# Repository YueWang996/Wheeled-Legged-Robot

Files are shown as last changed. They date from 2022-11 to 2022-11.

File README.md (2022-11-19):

# Wheeled Legged Robot
A low cost wheeled legged robot driven by BLDC motor and Feetech serial servos.
## Project Introduction
There are two branches in this project--_Main_ and _MotorDriver_

- Branch [Main](https://github.com/YueWang996/Wheeled-Legged-Robot/tree/main) contains code for the main control unit. It contains an ESP32 board and an MPU6050 6-DOF IMU. 
- Brance [MotorDriver](https://github.com/YueWang996/Wheeled-Legged-Robot/tree/MotorDriver) contains code based on SimpleFOC for the motor control board. It is a dual-channel BLDC motor controller which can control two BLDC motors at the same time. The onboard CAN transceiver receives instructions from the main control unit so that the two motors can move as desired. 

## Environment
- ESP-IDF 4.2
- CLion 2021.2.3
- Python 3.9

Maybe you can refer to [this link (Chinese version)](https://www.bilibili.com/read/cv15226500) to get more information about how to configure and use ESP-IDF toolchain in Clion. 

## Major Hardwares
- ESP32-WROOM-32D
- Feetech ST3215 serial servo * 4
- Feetech servo control board
- GY-521 (MPU6050)

## Project Structure
All source code is placed in the [src](https://github.com/YueWang996/Wheeled-Legged-Robot/tree/main/src).
 * [src](./src)
   * [CAN](./src/CAN) - CAN bus initialisation;
   * [MPU6050](./src/MPU6050) - MPU6050 drivers;
   * [ServoSDK](./src/ServoSDK) - Feetech servo driver modified for ESP32;
   * [imu.h/.cpp](./src) - IMU data acquire;
   * [Kalman.h/.cpp](./src) - A Kalman filter for data fusion of accelerometer and gyroscope readings from MPU6050, from TKJ Electronics;
   * [LowPass.h](./src) - A lowpass filter library from [here](https://github.com/curiores/ArduinoTutorials/blob/main/LowPass2.0/LowPass2.0.ino);
   * [MotorControl.h/.cpp](./src) - Controlling two BLDC motors and 4 servos to the desired position via CAN bus and serial port. Inverse kinematics is used to calculate servo positions;
   * [WebPage.h](./src) - HTML code for web interface rendering;
   * [Config.h](./src) - Some predefined static variables and data types;
   * [main.cpp](./src) - Main entrance of the program. COntaining the LQR controller.

All model files are stored in the directory [Models](https://github.com/YueWang996/Wheeled-Legged-Robot/tree/main/Models). They are already verified by 3D printing.

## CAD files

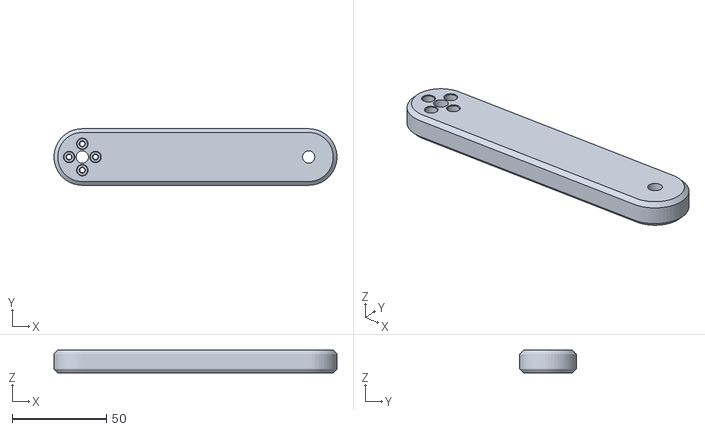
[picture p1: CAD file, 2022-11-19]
Models/leg_outside_up_servo.stl
150.0 x 30.0 x 12.0

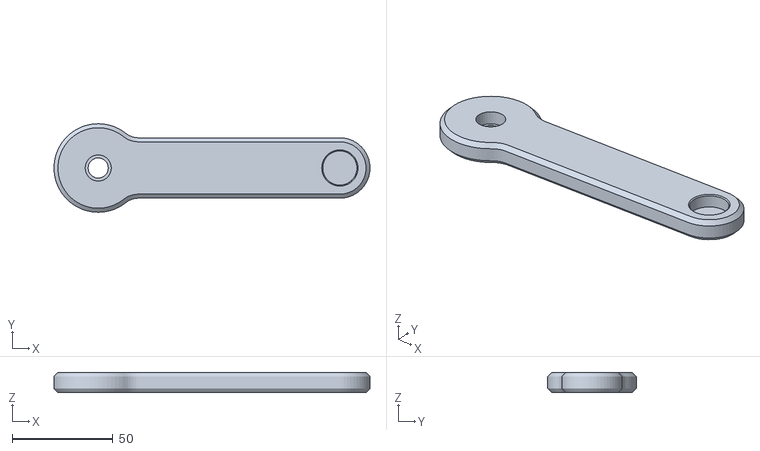
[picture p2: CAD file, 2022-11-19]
Models/leg_outside.stl
156.9 x 44.0 x 10.0

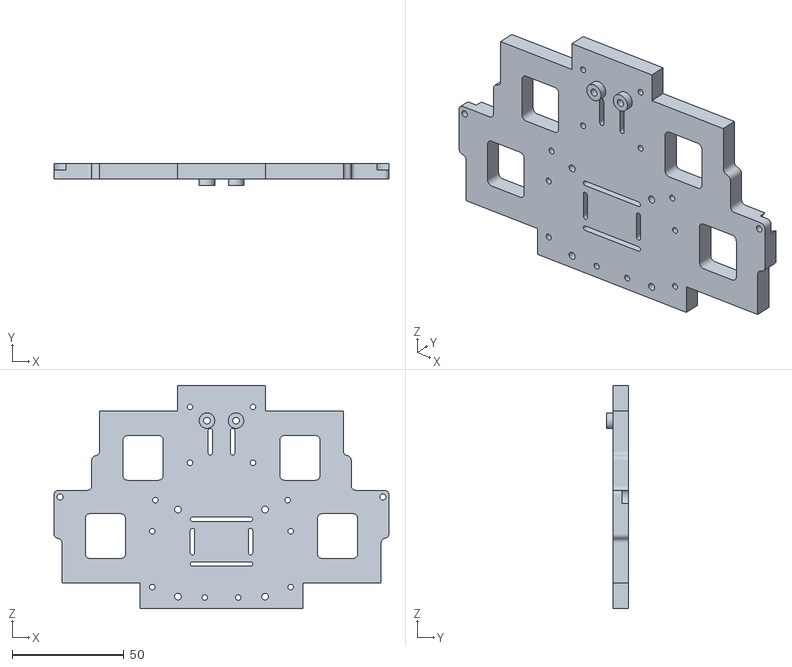
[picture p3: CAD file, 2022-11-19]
Models/body_base_servo.stl
150.0 x 10.0 x 100.0

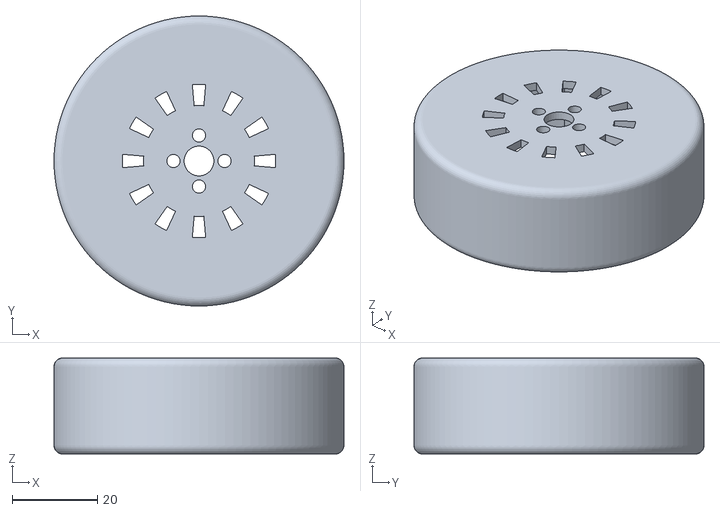
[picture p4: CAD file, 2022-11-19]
Models/wheel2.stl
68.0 x 68.0 x 22.5

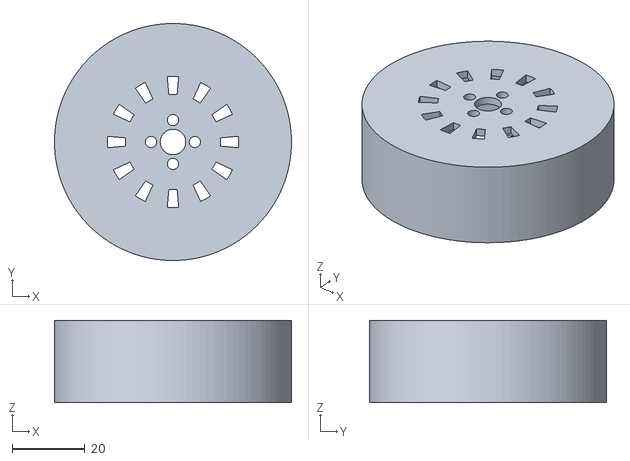
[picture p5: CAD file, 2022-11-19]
Models/wheel.stl
65.0 x 65.0 x 22.5

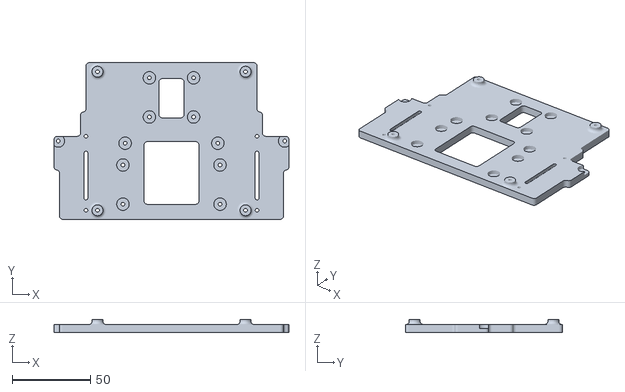
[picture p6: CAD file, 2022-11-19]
Models/body_top_servo.stl
150.0 x 100.0 x 8.00

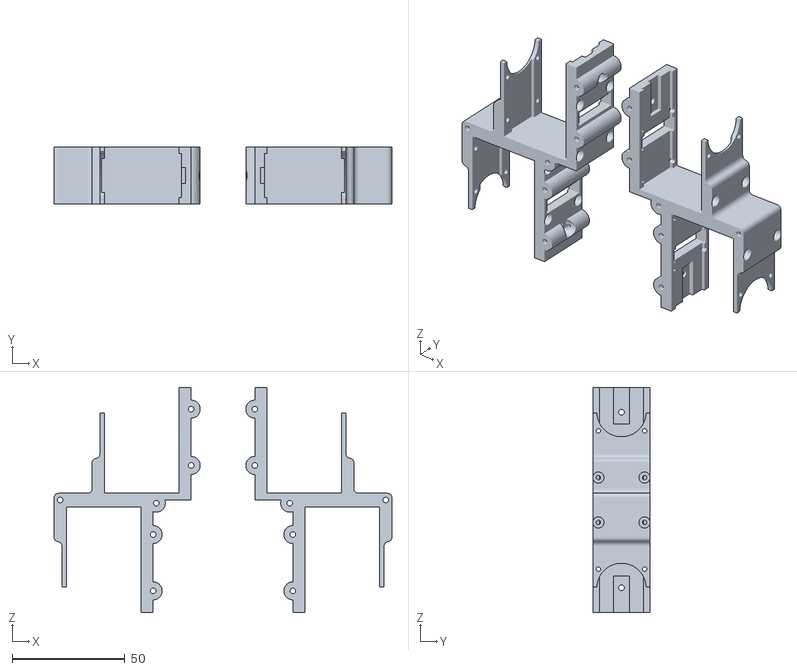
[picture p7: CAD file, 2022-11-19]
Models/body_servo.stl
150.0 x 25.5 x 100.0

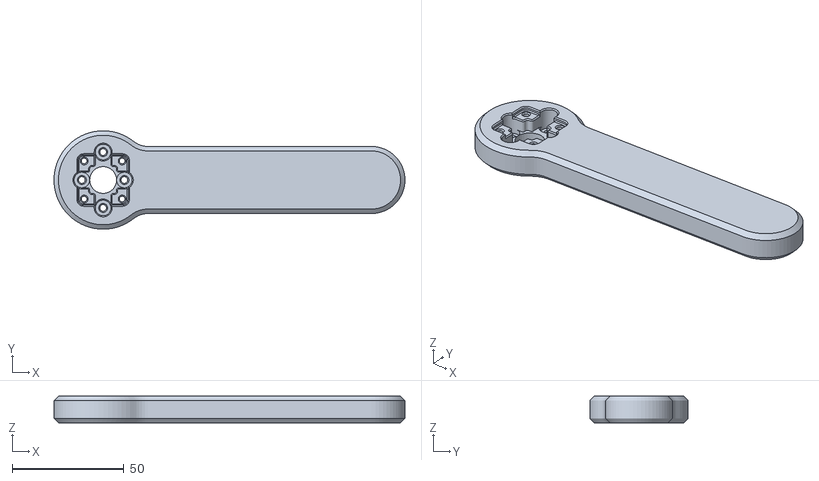
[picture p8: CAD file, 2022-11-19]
Models/leg_inside.stl
156.9 x 44.0 x 12.0

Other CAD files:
Models/leg_inside_up.stl
Models/leg_inside_up_servo.stl
Models/leg_outside_up.stl

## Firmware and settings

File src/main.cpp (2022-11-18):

#include <Arduino.h>
#include "freertos/FreeRTOS.h"
#include "freertos/task.h"
#include "freertos/timers.h"
#include "CAN/CAN_config.h"
#include "CAN/ESP32CAN.h"
#include "MotorControl.h"
#include "IMU.h"
#include "Kalman.h"
#include "soc/timer_group_struct.h"
#include "WebPage.h"

#include <WiFi.h>
#include <WebServer.h>
#include <sstream>

// #define WIFI_DEBUG

#ifdef WIFI_DEBUG
const char* ssid = "VM2866187";
const char* password = "tk8vyPczhfhr";
#else
const char* ap_ssid = "MengMengRobot";
const char* ap_password = "12345678";
#endif


WebServer server(80);

IPAddress PageIP(192, 168, 1, 1);
IPAddress gateway(192, 168, 1, 1);
IPAddress subnet(255, 255, 255, 0);
float target_position = 0;
float target_angle = 0;
float target_velocity = 0;
float height = 150.0;
bool ifJump = false;

CAN_device_t CAN_cfg;                // CAN Config
int rx_queue_size = 10;       // Receive Queue size

MotorControl motorControl;

IMU imu;
Kalman kalmanRoll;
Kalman kalmanPitch;
SCSCL sc(0);


static SIX_CHANNEL_BWLPF *bwlpf;
static float pitch, roll;
static double gyroXangle, gyroYangle; // Angle calculate using the gyro only
static double kalAngleX, kalAngleY; // Calculated angle using a Kalman filter
static double gyroY, gyroZ;
static double dt;
static ulong timer;

static TimerHandle_t motorControlTimer = nullptr;
void motorControlTimerCallback(TimerHandle_t xTimer);

void IMUDataProcessing(void *parameters);
void printIMUData(void *parameters);
void ledTask(void *parameters);
static void controlInit();

static void CAN_task(void *arg) {
    CAN_cfg.speed = CAN_SPEED_500KBPS;
    CAN_cfg.tx_pin_id = GPIO_NUM_2;
    CAN_cfg.rx_pin_id = GPIO_NUM_15;
    CAN_cfg.rx_queue = xQueueCreate(rx_queue_size, sizeof(CAN_frame_t));
    // Init CAN Module
    ESP32Can.CANInit();

    CAN_frame_t rx_frame;
    while(true) {
        //Serial.println("CAN while loop");
        if (xQueueReceive(CAN_cfg.rx_queue, &rx_frame, 3 * portTICK_PERIOD_MS) == pdTRUE) {
            //Serial.println("xQueueReceive");
            if (rx_frame.FIR.B.RTR == CAN_no_RTR) {
                motorControl.canDataDecode(rx_frame);
            }
            if (rx_frame.FIR.B.RTR == CAN_RTR) {
                //Serial.println("CAN_RTR");
                if(rx_frame.MsgID == BOARD_ID_1) {
                    //Serial.println("BOARD_01_IS_READY received");
                    CAN_frame_t tx_frame;
                    tx_frame.FIR.B.FF = CAN_frame_std;
                    tx_frame.MsgID = MASTER_RESPONSE;
                    tx_frame.FIR.B.RTR =CAN_RTR;
                    tx_frame.FIR.B.DLC = 0;
                    vTaskDelay(100 / portTICK_PERIOD_MS);
                    ESP32Can.CANWriteFrame(&tx_frame);

                    motorControl.BOARD_01_IS_READY = true;
                    double temp_Y = 0;
                    double temp_gyroY = 0;
                    for(uint16_t i = 0; i < 1000; i++) {
                        temp_Y += kalAngleY;
                        temp_gyroY += gyroY;
                        vTaskDelay(3 / portTICK_PERIOD_MS);
                    }

                    motorControl.mechanical_zero_angle = (temp_Y / 1000.0);
                    motorControl.zero_gyroY = (temp_gyroY / 1000.0);
                    motorControl.ch1_zero_position = motorControl.ch1_motor_position;
                    motorControl.ch2_zero_position = motorControl.ch2_motor_position;

                    motorControlTimer = xTimerCreate(
                            "motorControlTimer",
                            5 / portTICK_PERIOD_MS,
                            pdTRUE,
                            (void *) 0,
                            motorControlTimerCallback
                    );
                    if(motorControlTimer == nullptr) {
                        Serial.println("Could not create the motorControlTimer!");
                        while(1);
                    } else {
                        xTimerStart(motorControlTimer, portMAX_DELAY);
                    }
                }
            }
        }
    }
}


static void controlInit() {
    Serial2.begin(SERVO_BAUD_RATE); // TX: GPIO17, RX: GPIO16
    motorControl.initMotors(&sc);

    // pure angle loop: kp:200.2, ki:0.4, kd:5.5
    // add velocity loop: both kp and ki * 0.7
    motorControl.angleLoopPID.kp = 200.2;
    motorControl.angleLoopPID.ki = 0.41;
    motorControl.angleLoopPID.kd = 5.25;
    motorControl.angleLoopPID.error_sum_constrain = 20;
    motorControl.angleLoopPID.output_constrain = 100;

    motorControl.velocityLoopPID.kp = 0.0002;
    motorControl.velocityLoopPID.ki = 0.00006;
    motorControl.velocityLoopPID.kd = 0.00033;
    motorControl.velocityLoopPID.error_sum_constrain = 0.5;
    motorControl.velocityLoopPID.output_constrain = 0.5;

    motorControl.standing_loop_output = 0;
    motorControl.target_velocity = 0;
}

//Matrix<5,5> A_hat = {1.0, 0.005, 0, 0, 0,
//                     0.4083, 1.0, 0, 0, -0.4083,
//                     0, 0, 1.0, 0.005, 0,
//                     -0.0123, 0, 0, 1.0, 0.0123,
//                     0, 0, 0, 0, 1.0};  //I+ts*A_hat
//Matrix<5,1> B_hat = {0,
//                     -0.0278,
//                     0,
//                     0.0042,
//                     0}; //ts*B_hat
//Matrix<2,5> C_hat = {1,0,0,0,0,
//                     0,0,1,0,0};
//Matrix<5,5> A_LC = {-4.46, 0.005, 2.861, 0, 0,
//                    -298.5586, 1.0, 434.6414, 0, -0.4083,
//                    2.2012, 0, -36.3375, 0.005, 0,
//                    36.5914, 0, -220.8225, 1.0, 0.0123,
//                    29.6981, 0, -55.059, 0, 1.0};
//Matrix<5,2> L = {0.0650,   -0.0011,
//        0.6369 , -0.0062,
//        -0.0011,   0.0275,
//        -0.0184,   0.0227,
//        -0.0021,   0.0001};
//Matrix<1,5> K = {12.8, 28.5, 2.0, 8.0, 20.0};
//Matrix<5,5> E = {0.9350,   -0.0050,    0.0011,         0,         0,
//                 -1.4008,    0.2083,   -0.0494,   -0.2222,   -0.1472,
//                 0.0011 ,        0 ,   0.9725 ,  -0.0050 ,        0,
//                 0.0840 ,   0.1187 ,  -0.0144 ,   1.0333 ,   0.0711,
//                 0.0021 ,        0 ,  -0.0001 ,        0 ,   1.0000};
//Matrix<5,1> last_z, current_z;
//Matrix<2,1> y_m;

// LQR
//float lqr[4] = {0.0,0.1,-158.416857,-285.082587};
//float lqr[4] = {0.0,-2.0,-1238.4,-285.0};
float lqr[4] = {0.0,-2.0,-2538.4,-245.0};

float m1, m2;
float last_vel = 0;
float last_last_vel = 0;
float vel = 0;
float last_target;
float last_last_target;

float last_yaw = 0;
float alpha = 0.1;

float last_df = 0;
float last_phase_lead = 0;
void motorControlTimerCallback(TimerHandle_t xTimer) {
    //y_m(0,0) = kalAngleY - motorControl.mechanical_zero_angle;
    //y_m(1,0) = motorControl.ch1_motor_position - motorControl.ch1_zero_position;
    ////current_z = A_hat * last_z + B_hat * K * last_z + L * (y_m - C_hat * last_z);
    //current_z = E * last_z + L * y_m;
    //last_z = current_z;
    //Serial << '\t' << "d(4):" << current_z(4) << '\n' ;
    vel = 1.91122623f * last_vel + (-0.91500257f) * last_last_vel + (0.00094408f) * target_angle + (0.00188817f) * last_target + (0.00094408f) * last_last_target;
    last_last_vel = last_vel;
    last_vel = vel;
    last_last_target = last_target;
    last_target = target_angle;
    //if(target_angle == 0.0) {
    //    vel = 0; last_last_vel = 0; last_vel = 0;
    //    last_last_target = 0; last_target = 0;
    //}

    float yaw = target_velocity * alpha + (1.0f - alpha) * last_yaw;
    last_yaw = yaw;

    float df = (float)( ((motorControl.ch1_motor_position + motorControl.ch2_motor_position)/2.0f) * lqr[0]
                       + ((motorControl.ch1_motor_velocity + motorControl.ch2_motor_velocity)/2.0f - vel) * lqr[1]
                       + (kalAngleY - motorControl.mechanical_zero_angle) *lqr[2]
                       + (gyroY - motorControl.zero_gyroY) * lqr[3])*0.005f;

    //float phase_lead = 0.995 * df - 0.985 * last_df +0.98 * last_phase_lead;
    //last_df = df;
    //last_phase_lead = phase_lead;
    //float dv = 0.01 * (((motorControl.ch1_motor_velocity+motorControl.ch2_motor_velocity)*0.024/0.15) - target_velocity);
    m1 += (df);
    m2 += (df);

    /// Output limitation
    m1 = fast_constrain(m1, -100.0, 100.0);
    m2 = fast_constrain(m2, -100.0, 100.0);
    if(kalAngleY > 20 * (M_PI / 180.0) || kalAngleY < -20 * (M_PI / 180.0)) {
        m1 = 0;
        m2 = 0;
    }

    /// Send desired torque to motors
    if(motorControl.BOARD_01_IS_READY) {
        motorControl._tx_frame = motorControl.create2ChannelMotorTargetFrame(
                SET_TARGET,
                m1 + yaw,
                m2 - yaw);
        ESP32Can.CANWriteFrame(&motorControl._tx_frame);
    }

}

void RGB_Color(int i, int j, int k)
{
    ledcWrite(R_channel, i);
    ledcWrite(G_channel, j);
    ledcWrite(B_channel, k);
}

void ledTask(void *parameters){
    ledcAttachPin(LEDR, R_channel);
    ledcAttachPin(LEDG, G_channel);
    ledcAttachPin(LEDB, B_channel);
    ledcSetup(R_channel, pwm_Frequency, pwm_resolution);
    ledcSetup(G_channel, pwm_Frequency, pwm_resolution);
    ledcSetup(B_channel, pwm_Frequency, pwm_resolution);

    int i = 0;
    while(1) {
        for(i = 0; i < 200; ++i) {
            RGB_Color(i, 0, 0);
            delay(3);
        }
        for(i = 0; i < 200; ++i) {
            RGB_Color(200, i, 0);
            delay(3);
        }
        for(i = 0; i < 200; ++i) {
            RGB_Color(200, 200, i);
            delay(3);
        }
        for(i = 200; i > 0; --i) {
            RGB_Color(i, 200, 200);
            delay(3);
        }
        for(i = 200; i > 0; --i) {
            RGB_Color(0, i, 200);
            delay(3);
        }
        for(i = 200; i > 0; --i) {
            RGB_Color(0, 0, i);
            delay(3);
        }
    }
}

void printIMUData(void *parameters) {
    while(true) {
        //Serial.print("IMU_Pitch:");
        //Serial.print(kalAngleY);
        //Serial.print(",motorControl.target_torque:");
        //Serial.println(motorControl.target_torque);
        //Serial.print("IMU_Pitch:");Serial.println(kalAngleY - motorControl.mechanical_zero_angle);
        Serial.print("mechanical_zero_angle:");Serial.println(motorControl.mechanical_zero_angle);

        //Serial.print("Pos:");
        //Serial.print(((motorControl.ch1_motor_position - motorControl.ch1_zero_position) + target_position) * lqr[0]);
        //Serial.print(",Vel:");
        //Serial.print(-(motorControl.ch1_motor_velocity) * lqr[1]);
        //Serial.print(",Ang:");
        //Serial.print((kalAngleY - motorControl.mechanical_zero_angle + target_angle) *lqr[2]);
        //Serial.print(",Gyro:");
        //Serial.println((gyroY - motorControl.zero_gyroY) * lqr[3]);

        //Serial.print("position:");
        //Serial.print(motorControl.ch1_motor_position - motorControl.ch1_zero_position);
        //Serial.print(",velocity:");
        //Serial.println(motorControl.ch1_motor_velocity);

        //Serial.print(",CH1_Velocity:");
        //Serial.print(motorControl.ch1_motor_velocity);
        //Serial.print(",CH2_Velocity:");
        //Serial.print(motorControl.ch2_motor_velocity);
        //Serial.print(",CH1_Pos:");
        //Serial.print(motorControl.ch1_motor_position);
        //Serial.print(",CH2_Pos:");
        //Serial.println(motorControl.ch2_motor_position);
        vTaskDelay(500 / portTICK_PERIOD_MS);
    }
}

void handleRoot(){
    server.send(200, "text/html", webPage);
}

void rockerHandler() {
    String x_value_string = server.arg("x");
    String y_value_string = server.arg("y");
    float x_value = x_value_string.toFloat();
    float y_value = y_value_string.toFloat();
    target_angle = x_value;
    target_velocity = y_value;
    server.send(200, "text/plain", "");
}

void heightHandler() {
    String heightStr = server.arg("h");
    height = heightStr.toFloat();
    motorControl.setRobotHeight(0, height);
    delay(100);
    server.send(200, "text/plain", "");
}


void angleTuneHandler() {
    String direction = server.arg("angle");
    if(direction == "inc") {
        motorControl.mechanical_zero_angle += 0.005;
    } else if(direction == "dec") {
        motorControl.mechanical_zero_angle -= 0.005;
    }
    server.send(200, "text/plain", String(motorControl.mechanical_zero_angle, 5));
}

void lqrHandler() {
    String lqrpar = server.arg("lqr");
    int lqr_index = 0;
    int de_index = 0;
    for (int i = 0; i < lqrpar.length(); i++) {
        if (lqrpar.substring(i, i+1) == ",") {
            lqr[lqr_index] = lqrpar.substring(de_index, i).toFloat();
            de_index = i+1;
            lqr_index += 1;
        }
    }
    lqr[3] = lqrpar.substring(de_index, lqrpar.length()-1).toFloat();
    for (int i = 0; i < 4; ++i) {
        Serial.print(lqr[i]); Serial.print(",");
    }
    Serial.println();
    server.send(200, "text/plain", "");
}


//void jumpHandler() {
//    ifJump = true;
//    server.send(200, "text/plain", "");
//}



void handleNotFound(){
    server.send(404, "text/plain", "404: Not found");
}

static void WiFiTask(void *arg) {
    while(1) {
        server.handleClient();
    }
}

void setup() {
    delay(200);
    disableCore1WDT();

    Wire.setClock(100000);
    Wire.begin();

    Serial.begin(115200);
    imu.init(&Serial);
    bwlpf = imu.initializeBWLPF(2, 200, 50);
    roll = imu.getRoll();
    pitch = imu.getPitch();
    kalmanRoll.setQbias(0.005f);
    kalmanPitch.setQbias(0.005f);
    kalmanRoll.setAngle(roll);
    kalmanPitch.setAngle(pitch);
    gyroXangle = roll;
    gyroYangle = pitch;
    timer = micros();

    controlInit();

    //last_z.Fill(0);
    //current_z.Fill(0);
    //y_m.Fill(0);

    /// WiFi
#ifdef WIFI_DEBUG
    WiFi.mode(WIFI_MODE_STA);
    WiFi.begin(ssid, password);
    while(WiFi.status() != WL_CONNECTED) {
        delay(500);
        Serial.print(".");
    }
    Serial.println("");
    Serial.println("WiFi connected.");
    Serial.println("IP address: ");
    Serial.println(WiFi.localIP());
#else
    WiFi.softAP(ap_ssid, ap_password);
    delay(100);
    WiFi.softAPConfig(PageIP, gateway, subnet);
    delay(100);
    Serial.print("IP Address:"); Serial.println(WiFi.softAPIP());
#endif

    server.on("/", handleRoot);      //当访问服务器首页时，采用handleRoot函数处理
    server.on("/rocker", rockerHandler);
    server.on("/angle-tune", angleTuneHandler);
    //server.on("/jump", jumpHandler);
    server.on("/height", heightHandler);
    server.on("/lqr", lqrHandler);
    server.onNotFound(handleNotFound);  //如果访问对象不存在时，采用handleNotFound函数处理
    server.begin();

    Serial.print("HTTP server started");


    xTaskCreatePinnedToCore(WiFiTask,
                            "WiFiTask",
                            8192,
                            NULL,
                            1,
                            NULL,
                            1);

    xTaskCreatePinnedToCore(IMUDataProcessing,
                            "IMU Data Processing",
                            4096,
                            NULL,
                            1,
                            NULL,
                            0);

    xTaskCreatePinnedToCore(ledTask,
                            "ledTask",
                            800,
                            NULL,
                            1,
                            NULL,
                            0);

    //xTaskCreatePinnedToCore(printIMUData,
    //                        "Print IMU Data",
    //                        1024,
    //                        NULL,
    //                        1,
    //                        NULL,
    //                        0);

    xTaskCreatePinnedToCore(
            CAN_task,                   // Function to be called
            "CAN_task",         // Name of task
            4096,            // Stack size in byte
            NULL,            // Parameter to pass to function
            1,                  // Task priority
            NULL,            // Task handle
            0                   // Core id
    );

    vTaskDelete(nullptr);
}


void IMUDataProcessing(void *parameters) {
    double gyroXrate, gyroYrate;
    double temp_kalAngleX, temp_kalAngleY;
    float temp_roll, temp_pitch;
    while(true) {
        dt = (double)(micros() - timer) / 1000000; // Calculate delta time
        timer = micros();
        gyroXrate = imu.getGyroX();
        gyroYrate = imu.getGyroY();
        imu.ButterworthFilter(bwlpf);

        temp_pitch = imu.getPitch();
        temp_roll = imu.getRoll();
        if ((temp_roll < -90 && temp_kalAngleX > 90) || (temp_roll > 90 && temp_kalAngleX < -90)) {
            kalmanPitch.setAngle(temp_roll);
            temp_kalAngleX = temp_roll;
            gyroXangle = temp_roll;
        } else {
            temp_kalAngleX = kalmanPitch.getAngle(temp_roll, gyroXrate, dt); // Calculate the angle using a Kalman filter
        }

        if (abs(temp_kalAngleX) > 90) {
            gyroYrate = -gyroYrate; // Invert rate, so it fits the restriced accelerometer reading
        }
        //temp_kalAngleY = kalmanRoll.getAngle(temp_pitch, gyroYrate, dt);

        gyroXangle += gyroXrate * dt; // Calculate gyro angle without any filter
        gyroYangle += gyroYrate * dt;

        // Reset the gyro angle when it has drifted too much
        if (gyroXangle < -180 || gyroXangle > 180)
            gyroXangle = kalAngleX;
        if (gyroYangle < -180 || gyroYangle > 180)
            gyroYangle = kalAngleY;

        roll = temp_roll;
        pitch = temp_pitch;
        kalAngleX = temp_kalAngleX * (M_PI / 180.0);
        kalAngleY = temp_pitch * (M_PI / 180.0);
        //gyroZ = imu.getGyroZ() * (M_PI / 180.0);
        gyroY = imu.getGyroY() * (M_PI / 180.0);
    }
}


void loop() {
    vTaskDelay(2000/portTICK_PERIOD_MS);
}

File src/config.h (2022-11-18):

//
// Created by Justin on 28/03/2022.
//

#ifndef FOCX_CAN_TEST2_CONFIG_H
#define FOCX_CAN_TEST2_CONFIG_H

//#define ENABLE_BLDC_MOTORS

/// Command
#define REPORT_POSITION                 0b00100000001
#define REPORT_VELOCITY                 0b00100000011
#define SET_TARGET                      0b00100000010
#define MASTER_RESPONSE                 0b01000000001

#define BOARD_ID_1                      0x001

#define SERVO_BAUD_RATE                 115200
#define Z_AXIS_HEIGHT_MAX               230.0f
#define Z_AXIS_HEIGHT_MIN               140.0f
#define UPPER_LEG_LEN                   120.0f
#define LOWER_LEG_LEN                   120.0f
#define UPPER_SERVO_GAP                 79.71f
#define _SQ_UPPER_LEG                   14400.0f
#define _SQ_LOWER_LEG                   14400.0f
#define _SQ_SERVO_GAP                   6353.6841f

/// the number of the LED pin
#define LEDR 25
#define LEDG 26
#define LEDB 27
#define R_channel 0
#define G_channel 1
#define B_channel 2
#define pwm_Frequency 5000
#define pwm_resolution 8

typedef struct {
    float kp;
    float ki;
    float kd;
    float last_error;
    float error_sum;
    float error_sum_constrain;
    float output_constrain;
} PIDControlParameters;

typedef struct {
    int16_t ax, ay, az;
    int16_t gx, gy, gz;
} IMU_DATA;

typedef struct {
    int n;
    float *A;
    float *d1;
    float *d2;

    float *w10; float *w11; float *w12;
    float *w20; float *w21; float *w22;
    float *w30; float *w31; float *w32;
    float *w40; float *w41; float *w42;
    float *w50; float *w51; float *w52;
    float *w60; float *w61; float *w62;
} SIX_CHANNEL_BWLPF;

#endif //FOCX_CAN_TEST2_CONFIG_H

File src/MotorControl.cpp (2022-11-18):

//
// Created by Justin on 28/03/2022.
//

#include "MotorControl.h"

CAN_frame_t MotorControl::create2ChannelMotorTargetFrame(uint32_t msg_id, float ch1_target, float ch2_target) {
    CAN_frame_t tx_frame;
    tx_frame.FIR.B.FF = CAN_frame_std;
    tx_frame.FIR.B.RTR = CAN_no_RTR;
    tx_frame.MsgID = msg_id;
    tx_frame.FIR.B.DLC = 8;
    tx_frame.data.u8[0] = ((uint8_t *) &ch1_target)[0];
    tx_frame.data.u8[1] = ((uint8_t *) &ch1_target)[1];
    tx_frame.data.u8[2] = ((uint8_t *) &ch1_target)[2];
    tx_frame.data.u8[3] = ((uint8_t *) &ch1_target)[3];
    tx_frame.data.u8[4] = ((uint8_t *) &ch2_target)[0];
    tx_frame.data.u8[5] = ((uint8_t *) &ch2_target)[1];
    tx_frame.data.u8[6] = ((uint8_t *) &ch2_target)[2];
    tx_frame.data.u8[7] = ((uint8_t *) &ch2_target)[3];
    return tx_frame;
}

void MotorControl::connectIMU(IMU *imu) {
    _imu = imu;
}

void MotorControl::controlLoop() {
}

void MotorControl::canDataDecode(CAN_frame_t rx_frame) {
    if(rx_frame.MsgID == REPORT_VELOCITY) {
        ((uint8_t*)&ch1_motor_velocity)[0] = rx_frame.data.u8[0];
        ((uint8_t*)&ch1_motor_velocity)[1] = rx_frame.data.u8[1];
        ((uint8_t*)&ch1_motor_velocity)[2] = rx_frame.data.u8[2];
        ((uint8_t*)&ch1_motor_velocity)[3] = rx_frame.data.u8[3];
        ((uint8_t*)&ch2_motor_velocity)[0] = rx_frame.data.u8[4];
        ((uint8_t*)&ch2_motor_velocity)[1] = rx_frame.data.u8[5];
        ((uint8_t*)&ch2_motor_velocity)[2] = rx_frame.data.u8[6];
        ((uint8_t*)&ch2_motor_velocity)[3] = rx_frame.data.u8[7];
        ch1_motor_velocity *= -1.0f;
        ch2_motor_velocity *= -1.0f;
        ch1_motor_velocity = ch1_velocity_lpf.filter(ch1_motor_velocity);
        ch2_motor_velocity = ch2_velocity_lpf.filter(ch2_motor_velocity);
    }
    if(rx_frame.MsgID == REPORT_POSITION) {
        ((uint8_t*)&ch1_motor_position)[0] = rx_frame.data.u8[0];
        ((uint8_t*)&ch1_motor_position)[1] = rx_frame.data.u8[1];
        ((uint8_t*)&ch1_motor_position)[2] = rx_frame.data.u8[2];
        ((uint8_t*)&ch1_motor_position)[3] = rx_frame.data.u8[3];
        ((uint8_t*)&ch2_motor_position)[0] = rx_frame.data.u8[4];
        ((uint8_t*)&ch2_motor_position)[1] = rx_frame.data.u8[5];
        ((uint8_t*)&ch2_motor_position)[2] = rx_frame.data.u8[6];
        ((uint8_t*)&ch2_motor_position)[3] = rx_frame.data.u8[7];
        ch1_motor_position *= -1.0f;
        ch2_motor_position *= -1.0f;
    }

}

void MotorControl::initMotors(SCSCL *sc) {
    _sc = sc;
    //Serial2.begin(SERVO_BAUD_RATE); // TX: GPIO17, RX: GPIO16
    _sc->pSerial = &Serial2;
    for(int i = 0; i < 4; i++) {
        servo_position[i] = RAD_TO_SERVO_POS(0.0f);
        servo_speed_init[i] = 300;
        servo_speed[i] = 5000;
    }
    //vTaskDelay(2000 / portTICK_PERIOD_MS);
    //_sc->SyncWritePos(servo_id, 4, servo_position, servo_time, servo_speed_init);
    vTaskDelay(2000 / portTICK_PERIOD_MS);
    setRobotHeight(0, 155);
    vTaskDelay(1000 / portTICK_PERIOD_MS);
}

void MotorControl::inverseKinematics(float x, float z) {
    z = fast_constrain(z, Z_AXIS_HEIGHT_MIN, Z_AXIS_HEIGHT_MAX);
    float A_1_x = UPPER_SERVO_GAP / 2, A_1_z = 0;
    float A_2_x = -UPPER_SERVO_GAP / 2, A_2_z = 0;
    float e_1 = abs(A_1_z - z);
    float e_2 = abs(A_2_z - z);
    float f_1 = abs(A_1_x - x);
    float f_2 = abs(A_2_x - x);
    float sq_d1 = e_1 * e_1 + f_1 * f_1;
    float sq_d2 = e_2 * e_2 + f_2 * f_2;
    float sqrt_d1 = sqrtf(sq_d1);
    float sqrt_d2 = sqrtf(sq_d2);

    float B1_A1_P = acosf((sq_d1) / (2 * sqrt_d1 * UPPER_LEG_LEN));
    float B2_A2_P = acosf((sq_d2) / (2 * sqrt_d2 * UPPER_LEG_LEN));

    float P_A1_A2 = acosf((_SQ_SERVO_GAP + sq_d1 - sq_d2) / (2 * UPPER_SERVO_GAP * sqrt_d1));
    float A1_A2_P = acosf((_SQ_SERVO_GAP + sq_d2 - sq_d1) / (2 * UPPER_SERVO_GAP * sqrt_d2));
    float A2_P_B2 = acosf((sq_d2) / (2 * sqrt_d2 * LOWER_LEG_LEN));

    m_fl_target = M_PI_2 - (M_PI - P_A1_A2 - B1_A1_P);
    m_bl_target = M_PI_2 - (M_PI - A1_A2_P - B2_A2_P);
    m_fr_target = m_fl_target;
    m_br_target = m_bl_target;

    m_lw_offset = (A1_A2_P - A2_P_B2);
    m_rw_offset = m_lw_offset;
}

void MotorControl::setRobotHeight(float x, float height) {
    inverseKinematics(x, height);
    servo_position[0] = RAD_TO_SERVO_POS(m_fl_target);
    servo_position[1] = RAD_TO_SERVO_POS(m_fr_target * (-1));
    servo_position[2] = RAD_TO_SERVO_POS(m_bl_target * (-1));
    servo_position[3] = RAD_TO_SERVO_POS(m_br_target);
    _sc->SyncWritePos(servo_id, 4, servo_position, servo_time, servo_speed);

#ifdef ENABLE_BLDC_MOTORS
    _tx_frame = createMotorTargetFrame(BOARD_ID_1, CH_NUMBER1, 0.0);
    ESP32Can.CANWriteFrame(&_tx_frame);
    _tx_frame = createMotorTargetFrame(BOARD_ID_1, CH_NUMBER2, 0.0);
    ESP32Can.CANWriteFrame(&_tx_frame);
#endif
}

float MotorControl::PIDController(PIDControlParameters pid, float error) {
    float output;
    pid.error_sum += error;
    pid.error_sum = fast_constrain(pid.error_sum, -pid.error_sum_constrain, pid.error_sum_constrain);
    output = error * pid.kp + pid.error_sum * pid.ki + pid.kd * (error - pid.last_error);
    //printf("error:%0.2f, output:%.2f\n", error, output);
    output = fast_constrain(output, -pid.output_constrain, pid.output_constrain);
    pid.last_error = error;
    return output;
}

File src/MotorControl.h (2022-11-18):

//
// Created by Justin on 28/03/2022.
//

#ifndef FOCX_CAN_TEST2_MOTORCONTROL_H
#define FOCX_CAN_TEST2_MOTORCONTROL_H

#include "CAN/CAN_config.h"
#include "CAN/ESP32CAN.h"
#include "config.h"
#include "IMU.h"
#include "ServoSDK/SCServo.h"
#include "LowPass.h"

#define RAD_TO_SERVO_POS(x)             ((uint16_t)((x + 3.14159265) * 4095.0f / (6.28318527)))
#define fast_constrain(x, low, high)    ((x)<(low)?(low):((x) >(high)?(high):(x)))

class MotorControl {
public:
    MotorControl() = default;
    void initMotors(SCSCL *sc);
    void inverseKinematics(float x, float z);
    void setRobotHeight(float x, float height);

    CAN_frame_t create2ChannelMotorTargetFrame(uint32_t msg_id, float ch1_target, float ch2_target);
    void connectIMU(IMU *imu);
    void canDataDecode(CAN_frame_t rx_frame);
    void controlLoop();

    static float PIDController(PIDControlParameters pid, float error);

    SCSCL *_sc;
    uint8_t servo_id[4] = {1, 3, 5, 7};
    uint16_t servo_position[4] = {};
    uint16_t servo_speed_init[4] = {};
    uint16_t servo_speed[4] = {};
    uint16_t servo_time[4] = {0};

    float ch1_motor_position, ch2_motor_position;
    float ch1_motor_velocity, ch2_motor_velocity;

    IMU *_imu;

    CAN_frame_t _tx_frame;

    float m_fl_target;      // front left motor target
    float m_fr_target;      // front right motor target
    float m_bl_target;      // back left motor target
    float m_br_target;      // back right motor target
    float m_lw_target;      // left wheel sensor target
    float m_rw_target;      // right wheel sensor target

    float m_lw_offset;
    float m_rw_offset;

    PIDControlParameters angleLoopPID;
    PIDControlParameters velocityLoopPID;
    float velocity_loop_error_sum = 0;

    LowPass<2> ch1_velocity_lpf = LowPass<2>(1, 200, true);
    LowPass<2> ch2_velocity_lpf = LowPass<2>(1, 200, true);

    float target_velocity = 0;
    float standing_loop_output = 0;
    float mechanical_zero_angle = 0;
    float dead_zone_offset = 0.0;

    float ch1_zero_position = 0;
    float ch2_zero_position = 0;
    float zero_gyroY = 0;

    float target_torque = 0;
    float velocity_loop_output = 0;

    /// Motor board status
    bool BOARD_01_IS_READY = false;

};


#endif //FOCX_CAN_TEST2_MOTORCONTROL_H

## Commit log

2022-11-18 Control Unit with LQR control unit for the Leg-Wheeled robot
2022-11-19 Add files via upload
    STL models for the robot
    [body_base_servo.stl, body_servo.stl, body_top_servo.stl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]
